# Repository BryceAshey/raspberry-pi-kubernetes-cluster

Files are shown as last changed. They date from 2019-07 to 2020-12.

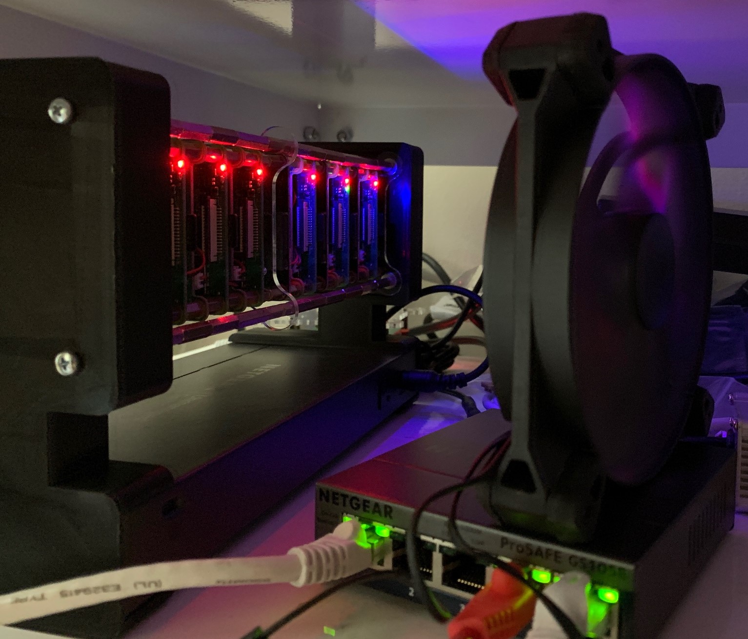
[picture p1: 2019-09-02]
designs/cluster-cooling-fan.jpg

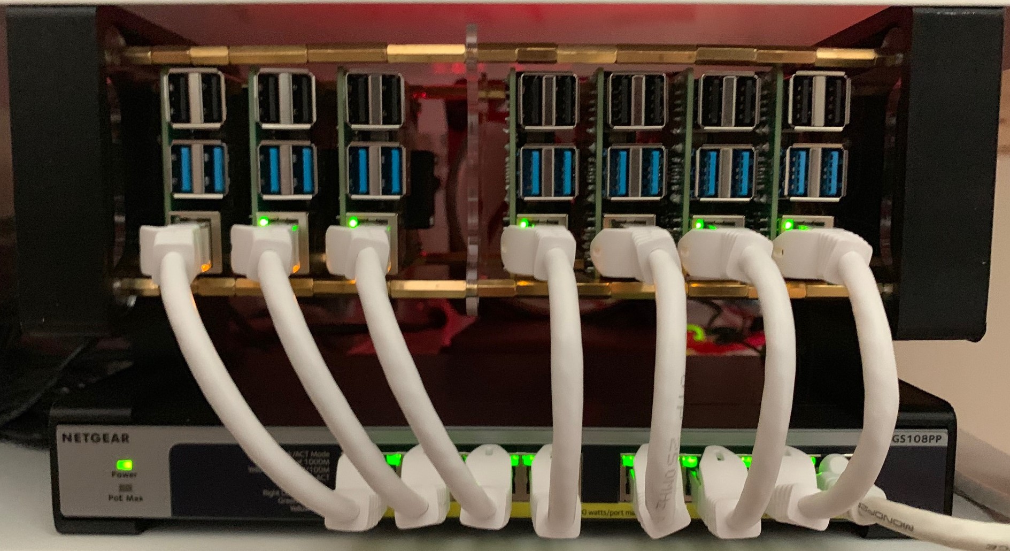
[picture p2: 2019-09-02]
designs/cluster.jpg

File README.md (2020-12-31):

# Raspberry PI Based Kubernetes Cluster
Designs, instructions, and more for a seven node Raspberry PI Kubernetes cluster.

As an enclosure alternative, [Uptime Labs released the STL files](https://uplab.pro/2020/12/raspberry-pi-server-mark-iii/) for a 19" rackmount that fits 14 Raspberry Pis.

PI Cluster

**Total Build Time:** Expert < 1 week / Newbie 4 weeks

### [Physical Construction](docs/construction.md)
When using the 3D printed brackets it is possible to squeeze 7 Raspberry PIs across the length of the POE switch. Doing so makes for a tidy little cluster that will fit on most bookshelves.

### [All Node Setup](docs/all-node-setup.md)
Each node requires some basic setup to prep it for use with Kubernetes.

### [Master Node Setup](docs/master-node-setup.md)
The master nodes utilize Keepalive and HAProxy to ensure the node address (192.168.200.249 in this example) is always online. 

### [Kubernetes Setup](docs/kubernetes-setup.md)
In this section we setup kubernetes on the first master node then join the subsequent master and worker nodes to it. Be sure to copy the certificates from kuber04m01 to the other master nodes. Do NOT copy the certificates to the worker nodes.

### [Gluster Setup](docs/gluster-setup.md)
In this implementation we use [Gluster](https://gluster.org) as the backing filesytem for Kubernetes Persistent Volumes. Gluster provides a fault-tolerant system across commodity and disparate hardware.

## Additional Reading
- [Igor Cicimov's Kubernetes cluster step-by-step](https://icicimov.github.io/blog/kubernetes/Kubernetes-cluster-step-by-step/)
- [Securing Raspbian](https://www.raspberrypi.org/documentation/configuration/security.md)
- [HAProxy Web Server on Raspbian](http://gregtrowbridge.com/setting-up-a-multiple-raspberry-pi-web-server-part-5/)
- [High Availability HAProxy](https://www.digitalocean.com/community/tutorials/how-to-create-a-high-availability-haproxy-setup-with-corosync-pacemaker-and-floating-ips-on-ubuntu-14-04)
- [Known HAProxy won't start issue](https://discourse.haproxy.org/t/haproxy-wont-start-properly/1394)
- [K8s on Rasbian](https://github.com/teamserverless/k8s-on-raspbian/blob/master/GUIDE.md)
- [Kubernetes High Availability](https://kubernetes.io/docs/setup/production-environment/tools/kubeadm/high-availability/)
- [Flannel](https://blog.laputa.io/kubernetes-flannel-networking-6a1cb1f8ec7c)
- [CIFS Volumes](https://github.com/fstab/cifs)

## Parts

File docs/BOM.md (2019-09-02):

# Bill of Materials

### Compute
- 7 [Raspberry PI 4 Model B+ w/4GB RAM](https://www.raspberrypi.org/products/raspberry-pi-4-model-b/)
- 7 [Raspberry PI POE HAT](https://www.amazon.com/gp/product/B07GR9XQJH/ref=ppx_yo_dt_b_asin_title_o01_s01?ie=UTF8&psc=1)
- 7 [SanDisk 64GB SD](https://www.amazon.com/gp/product/B07FCMBLV6/ref=ppx_yo_dt_b_asin_title_o03_s00?ie=UTF8&psc=1)

### Network
- 1 [Netgear GS108PP 8-port unmanaged switch w/POE](https://www.amazon.com/gp/product/B07788WK5V/ref=ppx_yo_dt_b_asin_title_o01_s00?ie=UTF8&psc=1) 
- 7 [6" Cat6 Ethernet Cables](https://www.amazon.com/gp/product/B00AJHCAPC/ref=ppx_yo_dt_b_asin_title_o01_s00?ie=UTF8&psc=1)

### Mounting Hardware
- 2 [3D Printed Mounts (left & right)](https://github.com/BryceAshey/raspberry-pi-kubernetes-cluster/tree/master/designs)
- 1 [GeauxRobot Dog Bone](https://www.amazon.com/GeauxRobot-Raspberry-Model-4-layer-Enclosure/dp/B00MYFAAPO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)
- 100pcs M2.5 x 10mm + 6mm Brass Standoffs Male to Female
- [Assorted M2.5 Brass Standoffs](https://www.amazon.com/gp/product/B075K3QBMX/ref=ppx_yo_dt_b_asin_title_o02_s00?ie=UTF8&psc=1)
- [Assorted M3 Standoffs](https://www.amazon.com/gp/product/B013ZWM1F6/ref=ppx_yo_dt_b_asin_title_o03_s00?ie=UTF8&psc=1)

### Optional Cooling
- 1 [Antec TrueQuiet 120mm Case Cooling Fan](https://www.amazon.com/gp/product/B004AGXHE6/ref=ppx_yo_dt_b_asin_title_o00_s00?ie=UTF8&psc=1)
- 1 [12v DC Fan Power Supply](https://www.amazon.com/gp/product/B07MZP9247/ref=ppx_yo_dt_b_asin_title_o07_s00?ie=UTF8&psc=1)

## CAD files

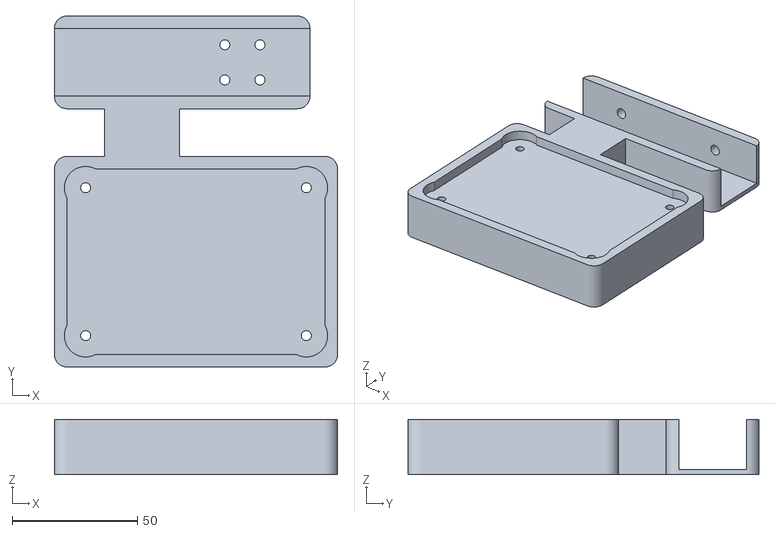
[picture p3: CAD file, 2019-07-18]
designs/netgear-pi-mount-left.stl
113.0 x 140.0 x 22.0

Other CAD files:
designs/netgear-pi-mount-right.stl

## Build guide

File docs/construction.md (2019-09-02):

# Building the Cluster

[**Bill of Materials**](docs/BOM.md)

Constructing the physical parts of the cluster is fairly straightforward once the mounts are printed.

## Printing the Switch Rack Mounts

Each mount should be printed with PLA. I used a .4 mm nozzle on an Ultimaker 2+ Extended (any printer should work though).

- [Left Mount](https://github.com/BryceAshey/raspberry-pi-kubernetes-cluster/blob/master/designs/netgear-pi-mount-left.stl)
- [Right Mount](https://github.com/BryceAshey/raspberry-pi-kubernetes-cluster/blob/master/designs/netgear-pi-mount-right.stl)

## Putting it all Together

As can be seen in the image below I used three parts of the GeauxRobot Dogbone case: one on each end and one in the middle. This allowed for good rigidity throughout the structure.

I then used M3 standoffs for the connecting rails.

The PIs themselves are mounted to either the left or the right Dogbone with M2.5 x 10mm + 6mm standoffs between the boards (including the POE hats).

## Connecting the Electrical

Once the physical structure is in place go ahead and connect the 6" ethernet cables to the switch and each PI. Connect your network to the far right port of the switch.

Finally, connect up the power cable and watch the PIs come up.

Regarding the optional cooling fan - it is not required but I found it to MUCH quieter with than the POE fans. For now I have that standing on another small switch behind the cluster. I'll work on adding mounts for that fan and it's power supply at some point in the future. If you choose to add the fan be sure to angle it slightly so that all the PI "blades" get air pushed across them.

PI Cluster

PI Cluster Cooling Fans

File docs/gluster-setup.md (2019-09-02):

# Gluster
[Gluster](https://www.gluster.org/) is a wonderful storage system built to run on commodity hardware. This makes it the perfect solution for a persistent volume file system for kubernetes (you can't get much more "commodity" than a PI). For this example we're just going to use a file system off the root SD card however you may wish to use a USB drive off the USB 3.1 ports in order to save the health of your SD cards and too avoid contention.

NOTE: In the example below we are installing the gluster server on the worker nodes as well. While this allows connectivity to gluster from the kubernetes pods on the worker nodes we really only need the [Gluster Client](https://docs.gluster.org/en/latest/Administrator%20Guide/Setting%20Up%20Clients/) installed. I'll refine the implementation at a later date.

Additional Reference: [Gluster on ARM](https://www.gopeedesignstudio.com/2018/07/13/glusterfs-on-arm/)

## Gluster Setup

Install GlusterFS (every node)
```
> sudo modprobe fuse
> sudo apt-get install -y xfsprogs glusterfs-server
```

Make sure Gluster is started (every node)
```
> sudo systemctl start glusterd
```

Peer all nodes together (run from kuber04m01)
```
> sudo gluster peer probe kuber04m02
> sudo gluster peer probe kuber04m03
> sudo gluster peer probe kuber04w01
> sudo gluster peer probe kuber04w02
> sudo gluster peer probe kuber04w03
> sudo gluster peer probe kuber04w04
```

Validate all peers are connected
```
> sudo gluster peer status

Number of Peers: 6

Hostname: kuber04m03
Uuid: c251f7f7-4682-4ccf-81d1-39bf9961cc12
State: Peer in Cluster (Connected)

Hostname: kuber04w02
Uuid: 27cd9ef1-7218-4d0b-9ad6-46cc187bf026
State: Peer in Cluster (Connected)

Hostname: kuber04m02
Uuid: d70f992b-5295-41b7-9992-38f3be627d98
State: Peer in Cluster (Connected)

Hostname: kuber04w03
Uuid: f5680983-5ad3-4c47-bad7-51bb96b2182e
State: Peer in Cluster (Connected)

Hostname: kuber04w01
Uuid: a71db145-5f43-4412-9da0-8f1de1e6ab1c
State: Peer in Cluster (Connected)

Hostname: kuber04w04
Uuid: 365fc2c9-7b3f-4874-90e5-708387744cc2
State: Peer in Cluster (Connected)

```

## Gluster Volume Setup

Create the first volume directory (all master nodes)
```
> sudo mkdir -p /data/glusterfs/myvol1/brick1/

```

(Optionally format and mount external storage device to above directory here...)

Create the first volume
```
> sudo gluster volume create brick1 kuber04m01:/data/glusterfs/myvol1/brick1/ kuber04m02:/data/glusterfs/myvol1/brick1/ kuber04m03:/data/glusterfs/myvol1/brick1/ 
```

Validate the volume setup

**Make note of the TCP port - you will need it to setup the endpoint in Kubernetes**

```
> sudo gluster volume status

Status of volume: jenkins
Gluster process                             TCP Port  RDMA Port  Online  Pid
------------------------------------------------------------------------------
Brick kuber04m01:/data/glusterfs/myvol1/brick1/    49152     0          Y       15088
Brick kuber04m02:/data/glusterfs/myvol1/brick1/    49152     0          Y       27562
Brick kuber04m03:/data/glusterfs/myvol1/brick1/    49152     0          Y       25493

Task Status of Volume jenkins
------------------------------------------------------------------------------
There are no active volume tasks

```

## Setup Kubernetes

Create the gluster endpoints in kubernetes. In the example below be sure to update the IPs to match your network and update the port to match the value from the output above.

```
> sudo nano glusterfs-endpoints.json

# paste the following and save 
{
  "kind": "Endpoints",
  "apiVersion": "v1",
  "metadata": {
    "name": "glusterfs-cluster"
  },
  "subsets": [
    {
      "addresses": [
        {
          "ip": "192.168.200.250"
        }
      ],
      "ports": [
        {
          "port": 49152
        }
      ]
    },
    {
      "addresses": [
        {
          "ip": "192.168.200.251"
        }
      ],
      "ports": [
        {
          "port": 49152
        }
      ]
    },
    {
      "addresses": [{ "ip": "192.168.200.252" }],
      "ports": [{ "port": 49152 }]
    }
  ]
}
```

Add the endpoint to kubernetes
```
> sudo kubectl create -f glusterfs-endpoints.json
```

Validate
```
> kubectl get endpoints

NAME                ENDPOINTS                                                           AGE
glusterfs-cluster   192.168.200.250:49152,192.168.200.251:49152,192.168.200.252:49152   23h
kubernetes          192.168.200.250:6443,192.168.200.251:6443,192.168.200.252:6443      24h
```

## Create a Persistent Volume

Create a volume for your pods to use. Note the **path** matches the "brick1" name from above.
```
> sudo nano brick1-volume.yaml

# paste

apiVersion: v1
kind: PersistentVolume
metadata:
  name: jenkins
  annotations:
    pv.beta.kubernetes.io/gid: "0"
spec:
  capacity:
    storage: 5Gi
  accessModes:
    - ReadWriteMany
  glusterfs:
    endpoints: glusterfs-cluster
    path: brick1
    readOnly: false
  persistentVolumeReclaimPolicy: Retain
```

Create the volume
```
> kubectl create -f brick1-volume.yaml
```

## Create a Persistent Volume Claim

```
> sudo nano brick1-pvc.yaml

# paste

apiVersion: v1
kind: PersistentVolumeClaim
metadata:
  name: brick1-gluster-claim
spec:
  accessModes:
  - ReadWriteMany
  resources:
     requests:
       storage: 1Gi
```

Create the claim
```
> kubectl create -f brick1-pvc.yaml
```

Validate
```
> kubectl get persistentVolumes

NAME      CAPACITY   ACCESS MODES   RECLAIM POLICY   STATUS   CLAIM                           STORAGECLASS   REASON   AGE
brick1   5Gi        RWX            Retain           Bound    default/brick1-gluster-claim                           18h
```

### Example spec for using the volume

In the example below we are assigning the Persistent Volume "brick1" to the jenkins_home mount path in the jenkins image.

Note: if you're going to try to setup Jenkins on ARM (i.e. the PI) be sure to use the jenkins4eval/jenkins image since it is the only one with ARM support.

```
    spec:
      containers:
      - name: jenkins
        image: jenkins4eval/jenkins
        ports:
          - containerPort: 8080
        volumeMounts:
        - name: brick1-home
          mountPath: /var/jenkins_home
          readOnly: false
      volumes:
      - name: brick1-home
        persistentVolumeClaim:
          claimName: brick1-gluster-claim
```

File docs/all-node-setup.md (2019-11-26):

# Node Setup

### Raspberry PI Image
Download the [Raspbian Buster Lite](https://downloads.raspberrypi.org/raspbian_lite/images/raspbian_lite-2019-07-12/2019-07-10-raspbian-buster-lite.zip) image onto your SD card and boot your PIs up.

### Via raspi-config:
- update hostname
- expand filesystem
- enable ssh
- update timezone as appropriate

### General Setup
We highly recommend reading Raspberry's [guidance](https://www.raspberrypi.org/documentation/configuration/security.md) on security best practices.

If in the US update your keyboard to "US"
```
> sudo nano /etc/default/keyboard
```

Create the Kubernetes admin user and add the user to sudo'ers
```
> sudo adduser kadmin
> sudo adduser kadmin sudo
```

Exit and login as kadmin

Delete the default user
```
> sudo deluser pi
```

Require sudo password on kadim. Change "pi" to "kadmin" in the file below
```
> sudo nano /etc/sudoers.d/010_pi-nopasswd
```

Optionally you may want to install [fail2ban](https://www.fail2ban.org/wiki/index.php/Main_Page) to lock the account after a number of tries...

Make dang sure that swap is turned off. Previously we could simply disable it as below but with Buster it appears that we need to now set swapsize = 0 to truly disable it.
```
> sudo dphys-swapfile swapoff
> sudo dphys-swapfile uninstall
> sudo update-rc.d dphys-swapfile remove

> sudo nano /etc/dphys-swapfile
# find CONF_SWAPSIZE=100 and change it to CONF_SWAPSIZE=0
```

Configure cgroup
```
> sudo nano /boot/cmdline.txt
# add the below line to the end of the existing text. Make sure to put a space (not carriage return) after the last value and the values below:
 cgroup_enable=cpuset cgroup_memory=1 cgroup_enable=memory
```

Disable the WIFI adapter
```
> echo "dtoverlay=pi3-disable-wifi" | sudo tee -a /boot/config.txt
```

Setup iptables to forward packets (required by Kubernetes networking)
```
> sudo iptables -P FORWARD ACCEPT
```

Add the above line to /etc/rc.local so that it gets reset on every boot
```
> sudo nano /etc/rc.local
# Paste the following line above "Exit 0" and make sure the top of the file has "#!/bin/sh -e"
/sbin/iptables -P FORWARD ACCEPT
```

Allow non-local bind (required by HAProxy)
Allow bridge to call iptables
```
> sudo sysctl net.ipv4.ip_nonlocal_bind = 1
> sudo sysctl net.bridge.bridge-nf-call-iptables=1
```

On each node configure your networking with a static IP. Alternatively you could configure DHCP on your router to assign a static IP to each server. Change the IPs in the list below to match your assignments.
```
> sudo nano /etc/hosts

# paste the following values at the end of the file
192.168.200.249 kubernetes
192.168.200.250 kuber04m01
192.168.200.251 kuber04m02
192.168.200.252 kuber04m03
192.168.200.230 kuber04w01
192.168.200.231 kuber04w02
192.168.200.232 kuber04w03
192.168.200.233 kuber04w04
```

Update your distribution
```
> sudo apt-get update
> sudo apt-get upgrade
```

Free up some space
```
> sudo apt-get -y purge "pulseaudio*"
```

Reboot to make sure everything is fresh
```
> sudo reboot now
```

## Install Docker and Kubernetes

### Install Docker

Note the hack here to install 9 instead of 10 on Buster. At the time of this writing there was not yet an ARM64 version of Docker compiled for Buster.
```
> curl -sL get.docker.com | sed 's/9)/10)/' | sh

# Once an ARM64 version is available the standard command (below) should work again
# curl -sSL get.docker.com | sh
```

Add kadmin to the docker group
```
> sudo usermod kadmin -aG docker
```

### Install Kubernetes

```
> curl -s https://packages.cloud.google.com/apt/doc/apt-key.gpg | sudo apt-key add - && \
  echo "deb http://apt.kubernetes.io/ kubernetes-xenial main" | sudo tee /etc/apt/sources.list.d/kubernetes.list && \
  sudo apt-get update -q && \
  sudo apt-get install -qy kubeadm
```

On the **master** nodes only; prepull the images for kubernetes
```
> sudo kubeadm config images pull -v3
```

### [Optional] Enable CIFS volumes
```
> sudo apt-get install -y jq
> VOLUME_PLUGIN_DIR="/usr/libexec/kubernetes/kubelet-plugins/volume/exec"
> sudo mkdir -p "$VOLUME_PLUGIN_DIR/fstab~cifs"
> cd "$VOLUME_PLUGIN_DIR/fstab~cifs"
> sudo curl -L -O https://raw.githubusercontent.com/fstab/cifs/master/cifs
> sudo chmod 755 cifs

# Verify the installation
> $VOLUME_PLUGIN_DIR/fstab~cifs/cifs init
```

Reboot again - ran into an issue once or twice when I didn't reboot
```
> sudo reboot now
```

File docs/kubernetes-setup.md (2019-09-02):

# Kubernetes Setup

## First Master Node (kuber04m01)

Perform the initial Kubernetes setup. As before, change the controlPlaneEndpoint to match your setup.

```
> sudo nano kubeadm-config.yaml
# paste the following

apiVersion: kubeadm.k8s.io/v1beta2
kind: ClusterConfiguration
kubernetesVersion: stable
controlPlaneEndpoint: "192.168.200.249:443"
networking:
  podSubnet: 10.244.0.0/16
apiServer:
  certSANs:
  - kubernetes
```

Initialize the Kubernetes cluster
```
> sudo kubeadm init --config=kubeadm-config.yaml --upload-certs -v 4
```

Configure your local kubectl. If for some reason you have to start over and issue a **kubeadm reset** you will need to do this again. **Make note of the join commands** that are presented once this command completes.

```
# from ~

> mkdir -p $HOME/.kube
> sudo cp -i /etc/kubernetes/admin.conf $HOME/.kube/config
> sudo chown $(id -u):$(id -g) $HOME/.kube/config
```

Install [Flannel](https://coreos.com/flannel/docs/latest/) as the networking component of the cluster
```
> kubectl apply -f https://raw.githubusercontent.com/coreos/flannel/master/Documentation/kube-flannel.yml

```

Copy the cluster certs to the other master nodes
```
> sudo apt install sshpass

> sudo sshpass -p "<your password>" scp /etc/kubernetes/pki/ca.crt kadmin@kuber04m02: && sudo sshpass -p "<your password>" scp /etc/kubernetes/pki/ca.key kadmin@kuber04m02: && sudo sshpass -p "<your password>" scp /etc/kubernetes/pki/sa.key kadmin@kuber04m02: && sudo sshpass -p "<your password>" scp /etc/kubernetes/pki/sa.pub kadmin@kuber04m02: && sudo sshpass -p "<your password>" scp /etc/kubernetes/pki/front-proxy-ca.crt kadmin@kuber04m02: && sudo sshpass -p "<your password>" scp /etc/kubernetes/pki/front-proxy-ca.key kadmin@kuber04m02: && sudo sshpass -p "<your password>" scp /etc/kubernetes/pki/etcd/ca.crt kadmin@kuber04m02:etcd-ca.crt && sudo sshpass -p "<your password>" scp /etc/kubernetes/pki/etcd/ca.key kadmin@kuber04m02:etcd-ca.key

> sudo sshpass -p "<your password>" scp /etc/kubernetes/pki/ca.crt kadmin@kuber04m03: && sudo sshpass -p "<your password>" scp /etc/kubernetes/pki/ca.key kadmin@kuber04m03: && sudo sshpass -p "<your password>" scp /etc/kubernetes/pki/sa.key kadmin@kuber04m03: && sudo sshpass -p "<your password>" scp /etc/kubernetes/pki/sa.pub kadmin@kuber04m03: && sudo sshpass -p "<your password>" scp /etc/kubernetes/pki/front-proxy-ca.crt kadmin@kuber04m03: && sudo sshpass -p "<your password>" scp /etc/kubernetes/pki/front-proxy-ca.key kadmin@kuber04m03: && sudo sshpass -p "<your password>" scp /etc/kubernetes/pki/etcd/ca.crt kadmin@kuber04m03:etcd-ca.crt && sudo sshpass -p "<your password>" scp /etc/kubernetes/pki/etcd/ca.key kadmin@kuber04m03:etcd-ca.key
```

## Master Nodes 2 and 3 (kuber04m02 & kuber04m03)

Move the certs to the /etc/kubernets/pki path
```
sudo mv ca.crt /etc/kubernetes/pki && sudo mv ca.key /etc/kubernetes/pki && sudo mv sa.key /etc/kubernetes/pki && sudo mv sa.pub /etc/kubernetes/pki && sudo mv front-proxy-ca.crt /etc/kubernetes/pki && sudo mv front-proxy-ca.key /etc/kubernetes/pki && sudo mkdir /etc/kubernetes/pki/etcd && sudo cp etcd-ca.crt /etc/kubernetes/pki/etcd/ca.crt && sudo cp etcd-ca.key /etc/kubernetes/pki/etcd/ca.key
```

Join the master nodes to 01 using the join command from when you ran **kubeadm init**. Make sure it's the command with **--controlplane** in it.

To regenerate the join commands use:
```
> sudo kubeadm token create --print-join-command
```

Be sure to do the following after the join succeeds
```
> mkdir -p $HOME/.kube
> sudo cp -i /etc/kubernetes/admin.conf $HOME/.kube/config
> sudo chown $(id -u):$(id -g) $HOME/.kube/config
```

## All Worker Nodes

Join the worker nodes to 01 using the join command from when you ran **kubeadm init**. Make sure the command does **NOT** have **--controlplane** in it.

To regenerate the join commands use:
```
> sudo kubeadm token create --print-join-command
```

## Confirmation

You should be able to see the following response from kuber04m01
```
> kubectl get nodes

NAME         STATUS   ROLES    AGE   VERSION
kuber04m01   Ready    master   24h   v1.15.1
kuber04m02   Ready    master   24h   v1.15.1
kuber04m03   Ready    master   24h   v1.15.1
kuber04w01   Ready    <none>   23h   v1.15.2
kuber04w02   Ready    <none>   23h   v1.15.2
kuber04w03   Ready    <none>   23h   v1.15.2
kuber04w04   Ready    <none>   23h   v1.15.3
```

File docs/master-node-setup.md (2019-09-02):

# Master Node Setup

## Configure Keepalive
We use keepalive on each of the 3 master nodes to ensure a single static IP is available at all times for the Kubernetes API. If a node fails then keepalive will move the IP to one of the remaining "up" nodes. As with before change the IPs found within to meet your needs.

Install Keepalive
```
> sudo apt-get install keepalived
```

Configure Keepalive

Note: on each master node you need to change the "unicast_src_ip" to match the IP of the node. Then change the "unicast_peer_ip" to match the other two nodes.
```
> sudo nano /etc/keepalived/keepalived.conf

# replace with the following:
vrrp_script haproxy-check {
    script "killall -0 haproxy"
    interval 2
    weight 20
}
 
vrrp_instance haproxy-vip {
    state BACKUP
    priority 101
    interface eth0
    virtual_router_id 47
    advert_int 3
 
    unicast_src_ip 192.168.200.252
    unicast_peer {
        192.168.200.250
        192.168.200.251
    }
 
    virtual_ipaddress {
        192.168.200.249 
    }
 
    track_script {
        haproxy-check weight 20
    }
}

```

Reboot
```
> sudo reboot now
```

## HAProxy Setup
We use HAProxy to route traffic from the master node IP to the aforementioned keepalive IP (in this example 192.168.200.249).

Install HAProxy
```
> sudo apt-get install haproxy
```

Enable on Startup
```
> sudo nano /etc/default/haproxy
# Set	ENABLED=1
```
Configure HAProxy
The SSH proxy is optional - I found that sometimes HAProxy would interfere with SSH unless I put the proxy in. Something to figure out longer term.
```
> sudo nano /etc/haproxy/haproxy.cfg

# Edit with the following

global
        log 127.0.0.1:514  local0
        log 127.0.0.1:514  local0 notice
        chroot /var/lib/haproxy
        stats socket /run/haproxy/admin.sock mode 660 level admin expose-fd lis$
        stats timeout 30s
#       user haproxy
#       group haproxy
        daemon

        # Default SSL material locations
        ca-base /etc/ssl/certs
        crt-base /etc/ssl/private

        # Default ciphers to use on SSL-enabled listening sockets.
        # For more information, see ciphers(1SSL). This list is from:
        #  https://hynek.me/articles/hardening-your-web-servers-ssl-ciphers/
        # An alternative list with additional directives can be obtained from
        #  https://mozilla.github.io/server-side-tls/ssl-config-generator/?serv$
        ssl-default-bind-ciphers ECDH+AESGCM:DH+AESGCM:ECDH+AES256:DH+AES256:EC$
        ssl-default-bind-options no-sslv3

defaults
        log     global
        mode    tcp
        option  tcplog
        option  dontlognull
        timeout connect 1s
        timeout client  20s
        timeout server  20s
        timeout client-fin 20s
        timeout tunnel 1h
        errorfile 400 /etc/haproxy/errors/400.http
        errorfile 403 /etc/haproxy/errors/403.http
        errorfile 408 /etc/haproxy/errors/408.http
        errorfile 500 /etc/haproxy/errors/500.http
        errorfile 502 /etc/haproxy/errors/502.http
        errorfile 503 /etc/haproxy/errors/503.http
        errorfile 504 /etc/haproxy/errors/504.http

listen stats
  bind    *:9000
  mode    http
  stats   enable
  stats   hide-version
  stats   uri       /stats
  stats   refresh   30s
  stats   realm     Haproxy\ Statistics
  stats   auth      Admin:Password

frontend k8s-api
        bind 192.168.200.249:443
        bind 127.0.0.1:443
        mode tcp
        option tcplog
        default_backend k8s-api

frontend ssh-proxy
        bind 192.168.200.251:2222
        mode tcp
        option tcplog
        default_backend ssh-proxy-backend

backend k8s-api
        mode tcp
        server kuber04m01 192.168.200.250:6443 check
        server kuber04m02 192.168.200.251:6443 check
        server kuber04m03 192.168.200.252:6443 check

backend ssh-proxy-backend
        mode tcp
        server kuber04m02 192.168.200.251:22 check id 1
```

Reboot
```
> sudo reboot now
```

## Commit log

2019-07-18 added designs for left and right switch mounts
    [netgear-pi-mount-left.stl, netgear-pi-mount-right.stl]
2019-08-04 added bracket for storage mounts
    [geauxrobot-hook-pi-plate.stl]
2019-08-08 lengthened hook plate by 15mm to accomodate usb cable
    [geauxrobot-hook-pi-plate.stl]
2019-09-02 removed geauxrobot hook as it proved unneeded.
    [geauxrobot-hook-pi-plate.stl]
2019-09-02 moved bom to construction page
